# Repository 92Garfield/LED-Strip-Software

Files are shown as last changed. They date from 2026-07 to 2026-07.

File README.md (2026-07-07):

# gLED — WLAN LED Strip

NeoPixel strip on a Raspberry Pi Pico W (CircuitPython 9), controlled via browser extension.

## Folders

- `firmware/GEdge` — CIRCUITPY drive content (kitchen strip, 150 LEDs, `192.168.2.42`)
- `gLED-Client Chrome` — Chrome extension, **source of truth** for client `js/` + `css/`
- `gLED-Client Firefox` — Firefox extension (desktop + Android), only `manifest.json` differs
- `client/GEdge-html` — old on-controller web client (retired, kept for reference)

## Firmware (`firmware/GEdge`)

- Copy `src/config.example.py` to `src/config.py`, then set WiFi, IP, LED count, name, physical layout, and default animation
- `src/led_server.py` — HTTP server; serves one tiny HTML page exposing global `gLED`
- `src/animation_runner.py` — non-blocking animation loop beside the server
- `animations/*.py` — one class `Animation` per file (`start(now)` / `step(now)`)
  - `hue_cycle` — whole strip, hue rotates (interval + step configurable)
  - `fill_runner` — red runner right→left stacks until full, then back to blue
- `glib/color.py` — `hsv_to_rgb()` for NeoPixel
- Boot: connects WiFi, starts server, autostarts `config.DEFAULT_ANIMATION`

## HTTP API (`POST /data`, urlencoded, values NOT percent-encoded)

- `type=set` `data=r,g,b|r,g,b|…` — set all pixels (stops animation)
- `type=brightness` `data=1..100`
- `type=animation` `data=<name>` or `data=stop`
- `GET /` — HTML with `var gLED = {name, ledCount, length, physical, animations}`

## Clients (extensions)

- Run on the controller page, replace it entirely with their own UI
- Custom elements (`js/elements/`), built by `js/app.js`, dark CSS
- Show physical layout (y-up), tabs: Animation / Manual (tap LEDs to paint)
- No live data from server; last set state kept in `localStorage`
- Brightness slider in header

### Chrome

- `chrome://extensions` → Developer mode → Load unpacked → `gLED-Client Chrome`

### Firefox (desktop + Android)

- After client changes: run `gLED-Client Firefox/sync.ps1` (copies `js/`+`css/` from Chrome)
- Desktop test: `about:debugging` → Load Temporary Add-on
- Android: needs signed `.xpi` via addons.mozilla.org (unlisted) — see `gLED-Client Firefox/README.md`

## New controller / IP change

Update the IP in **3 places**:

- `gLED-Client Chrome/manifest.json` → `matches`
- `gLED-Client Firefox/manifest.json` → `matches` **and** `host_permissions`
- Firmware: `src/config.py` → `STATIC_IP`

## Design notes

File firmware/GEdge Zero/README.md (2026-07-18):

# GEdge Zero

HTTP-controlled WS2812/NeoPixel firmware for a **Raspberry Pi Zero family**
board (Zero W, Zero WH, Zero 2 W), driving up to **4 independent LED
strips** from the ["4-strips, 4-power" PCB](<../../PCB/simplified/4-strips, 4-power/pcb.md>).

This is the Pi Zero counterpart to [`../GEdge`](<../GEdge>) (which runs on a
Pico W under CircuitPython): same architecture (`src/` app code,
`animations/` step-based effects, `glib/` color helpers), but written in
regular Python 3 for Raspberry Pi OS, since the Pi Zero runs full Linux
rather than a microcontroller RTOS.

## Hardware

| Connector | GPIO (BCM) | Header pin | Peripheral | Firmware strip |
|---|---|---|---|---|
| J2 | GPIO18 | 12 | PWM0  | S1 |
| J4 | GPIO13 | 33 | PWM1  | S2 |
| J5 | GPIO10 | 19 | SPI0  | S3 |
| J3 | GPIO21 | 40 | PCM | S4 |

These four GPIOs were chosen because each is driven by a **different**
hardware peripheral capable of generating the WS2812 timing via DMA
(2x PWM, PCM, SPI) - so all four strips can run simultaneously without one
blocking another. See the PCB's `pcb.md` for the full board writeup, and
`J7-J10` for the power-only injection connectors on long strips.

## 1. Flash and boot Raspberry Pi OS

Use **Raspberry Pi OS Lite** (headless, no desktop) via Raspberry Pi
Imager. In the imager's settings (gear icon) before writing:
- Enable SSH
- Set your WiFi SSID/password
- Set a hostname/username/password

Boot the Pi and confirm you can SSH in:
```
ssh <username>@<hostname>.local
```

## 2. Enable SPI and free up the PCM/audio peripheral

Strip S3 (GPIO10) needs SPI enabled, and strip S4 (GPIO21) needs the
onboard audio disabled (it uses the same PCM peripheral and will conflict
with the LED timing otherwise).

```bash
sudo raspi-config
# Interface Options -> SPI -> Enable
```

Then edit `/boot/firmware/config.txt` (or `/boot/config.txt` on older OS
versions) and make sure audio is off:
```
dtparam=audio=off
```

Reboot after these changes: `sudo reboot`

## 3. Get the code onto the Pi

```bash
git clone <this repo's URL>
cd "LED-Strip-Software/firmware/GEdge Zero"
```

## 4. Install dependencies

`rpi_ws281x` needs root to access DMA/PWM, and building its C extension
needs a compiler - both are handled below.

```bash
sudo apt update
sudo apt install -y python3-pip python3-venv build-essential
python3 -m venv venv
source venv/bin/activate
pip install -r requirements.txt
```

## 5. Configure your strips

```bash
cp src/config.example.py src/config.py
nano src/config.py
```
Adjust `num_pixels`, `name`, `length_cm` and `physical` per strip to match
your actual strips (the GPIO/channel/dma values already match the PCB
table above - only change those if you rewired something).

## 6. Run it

`rpi_ws281x` requires root:

```bash
sudo venv/bin/python3 main.py
```

You should see each strip initialize and start its `DEFAULT_ANIMATIONS`
entry (rainbow by default). Visit `http://<hostname>.local/` from a
browser to confirm the server is up. The page is compatible with the gLED
Chrome/Firefox client: the first configured strip is exposed as the global
`gLED` object (and shown in the page body), additional strips as `gLED2`,
`gLED3`, `gLED4`; each object carries its `strip` value for the `/data`
field below.

### Control API

`POST /data` (form-encoded), same contract as GEdge, plus a `strip` field:

| Field | Values | Notes |
|---|---|---|
| `strip` | `S1`, `S2`, `S3`, `S4`, `all` | Which output to target. Defaults to `S1`. Ignored for `shutdown`. |
| `type` | `set`, `brightness`, `animation`, `shutdown` | `shutdown` powers off the Pi (safe to unplug once its LED stops blinking). |
| `data` | `"r,g,b\|r,g,b\|..."` (set) / `0-100` (brightness) / animation name or `stop` (animation) | Ignored for `shutdown`. |

## 7. Run automatically on boot (systemd)

Create `/etc/systemd/system/gedge-zero.service`:
```ini
[Unit]
Description=GEdge Zero LED controller
After=network-online.target

[Service]
Type=simple
WorkingDirectory=/home/<username>/LED-Strip-Software/firmware/GEdge Zero
ExecStart="/home/<username>/LED-Strip-Software/firmware/GEdge Zero/venv/bin/python3" main.py
Restart=on-failure
User=root

[Install]
WantedBy=multi-user.target
```

Then:
```bash
sudo systemctl daemon-reload
sudo systemctl enable --now gedge-zero.service
sudo journalctl -u gedge-zero -f   # follow logs
```

## Troubleshooting

- **`ws2811_init failed`**: another process is already using that DMA
  channel/peripheral, or SPI/audio wasn't configured per step 2. Check
  `dmesg` and confirm `dtparam=audio=off` and SPI is enabled.
- **Flicker / glitches on GPIO10 or GPIO21**: these carry 3.3 V logic
  straight into nominally-5 V strips (no level shifter on the simplified
  PCB) - keep data leads short, as noted in the PCB's `pcb.md`.
- **Strips don't turn off when you stop the script**: use `Ctrl+C` (SIGINT)
  or `systemctl stop`, not `kill -9` - the signal handler in `main.py`
  clears all strips on exit; `SIGKILL` skips it.

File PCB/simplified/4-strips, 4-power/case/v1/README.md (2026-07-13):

# 3D-printed case v1 — gLED Controller simple

Two-part case for `../../led-controller-simple.kicad_pcb`: a **tray** the PCB
screws into and a **friction-fit lid** with openings above every top-entry
connector. Outer size **90.8 × 75.8 × 34.4 mm** (tray + lid).

All geometry is parametric in `case.scad`; positions are copied from
`build_board.py` in KiCad board coordinates and mirrored automatically.

## Files

- `case.scad` — source (OpenSCAD 2021.01). `part` selects what to render:
  `"tray"`, `"lid"` (already flipped for printing) or `"assembly"`
  (tray + ghost board + hovering lid, for visual checks only).
- `case_tray.stl`, `case_lid.stl` — ready to slice, in print orientation.
- `preview_*.png` — renders of the assembly and both printable parts.

## Openings

| Where | For |
|---|---|
| Lid, right slot | J2–J5 strip plugs + wires (top-entry JST XH) |
| Lid, left slot | J7–J10 power-only plugs |
| Lid + top wall notch | J1 screw terminal: screwdriver from above, supply wires out of the top edge |
| Bottom wall slot | Pi Zero mini-HDMI / USB ports (Pi hangs under the PCB) |
| Left wall slot | Pi SD card |

## Printing

- No supports needed for either part; lid STL is already face-down.
- PLA or PETG, 0.2 mm layers, 3 perimeters. ~25 % infill is plenty.
- The lid lip has 0.3 mm clearance (`lip_clr`) — tighten/loosen to taste.

## Assembly

1. Mount the Pi on its M2.5 standoffs under the PCB (11 mm board-to-board).
2. Drop the PCB in and fasten with **4× M3 self-tapping screws** (8–10 mm)
   into the corner bosses (pilot holes Ø2.7 mm).
3. Wire J1 through the top-edge notch, plug in strips, press the lid on.

## Regenerating

```
openscad -o case_tray.stl -D "part=\"tray\"" case.scad
openscad -o case_lid.stl  -D "part=\"lid\""  case.scad
```

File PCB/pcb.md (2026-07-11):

# LED Controller PCB — KiCad files

Carrier board for a Raspberry Pi Zero 2 WH: 110 × 70 mm, 2 layers, 2 oz copper.
The board sits **on top of** the Pi like an oversized pHAT — the 2×20 socket is
on the back side, the Pi hangs underneath on M2.5 standoffs with its pins
pointing up into the socket. Design intent and part choices are in `plan.md`;
this file explains what each generated file is and what it means electrically.

## Source files

### `build_board.py`
The actual "source code" of the board. Running it with KiCad's bundled Python
regenerates `led-controller.kicad_pcb` from scratch — every footprint position,
net assignment, trace, zone and silkscreen label is defined here as code.
If you want to change the layout, change this script, not the `.kicad_pcb`
(manual edits in KiCad get overwritten on the next script run).

```
"D:/Program Files/KiCad/10.0/bin/python.exe" build_board.py
"D:/Program Files/KiCad/10.0/bin/python.exe" fill_zones.py
```

Electrically, the script defines these nets:

| Net | Meaning |
|---|---|
| `+5V` | Raw supply from J1. Feeds the Pi (header pins 2/4), U1's VCC, and all four fuse inputs. Distributed as wide copper pours, not traces, because worst case is ~20 A. |
| `GND` | Common return. Poured on both layers, stitched with vias. |
| `5V_S1`…`5V_S4` | The four **fused** 5 V outputs — everything after fuse Fx belongs to its own net so a blown fuse isolates exactly one strip. |
| `D18_3V3`, `D13_3V3`, `D10_3V3`, `D21_3V3` | 3.3 V logic from the Pi GPIOs (18/13/10/21) into the level shifter inputs. |
| `D1_5V`…`D4_5V` | 5 V logic out of the 74AHCT125, before the series resistor. |
| `DATA1`…`DATA4` | After the 470 Ω resistor, into JST pin 2 — what the first LED of each strip sees. |

Channel mapping (matches `plan.md` and the firmware): GPIO18 → S1/J2,
GPIO13 → S2/J3, GPIO10 → S3/J4, GPIO21 → S4/J5.

### `fill_zones.py`
Refills the copper zones after a rebuild. Separate script because KiCad's zone
filler crashes when called on a freshly built in-memory board (standalone
Python quirk) — it must load the saved file, fill, and save again. **Zones must
be filled** before export: unfilled zones would mean the Gerbers contain no
+5V/GND copper at all.

## Board files

### `led-controller.kicad_pcb`
The board itself — open this in KiCad (PCB Editor) to inspect or measure.
Layout, electrically:

- **Front (F.Cu), +5V pours**: a top strip from J1 across the board, a left
  strip feeding the Pi's 5 V pins, and a ~12 mm vertical bus feeding all four
  fuse inputs. Sized for 20 A total at 2 oz copper; the bus connects to the
  fuse clips solid (no thermal spokes) to minimize resistance.
- **Fuse rows**: each 5×20 mm fuse lies directly in line with its JST
  connector, so the fused current path is fuse clip → 2 mm trace → JST pin 1,
  a few millimetres long. No fused current crosses the rest of the board.
- **Data path**: Pi GPIO (through-hole header pads) → short front-side traces
  → 74AHCT125 inputs. The shifted 5 V outputs run on the **back** layer to the
  470 Ω resistors (also mounted on the back, next to the JSTs) → JST pin 2.
  Resistors sit close to the connectors on purpose: they damp reflections at
  the cable, which only works near the line's driving end.
- **GND**: full pours on both layers plus ~20 stitching vias. LED return
  current flows from JST pin 3 through these planes back to J1. The unused
  74AHCT125 enable pins (1, 4, 10, 13) are tied to GND via the back pour —
  outputs permanently enabled.
- **Mounting**: H1–H4 are the M2.5 Pi-pattern holes (58 × 23 mm), H5–H8 are M3
  case-mounting corner holes. All holes are unplated and carry no net.

### `led-controller.kicad_pro` / `.kicad_prl` / `~*.lck`
KiCad project settings, per-user display state, and an editor lock file.
No electrical content; the `.lck` just means the board is open in KiCad.
None of these are needed for manufacturing.

## Manufacturing outputs

### `gerbers/` and `led-controller-gerbers.zip`
The zip is what you upload to the fab (JLCPCB etc.) — it contains exactly the
files in `gerbers/`. Gerbers are the fab's ground truth; they describe
photomask geometry per layer, with no nets or components:

| File | Layer | Electrical meaning |
|---|---|---|
| `*-F_Cu.gtl` | Front copper | All top-side conductors: +5V pours, fused-output traces, data input traces, GND fill. |
| `*-B_Cu.gbl` | Back copper | Bottom conductors: GND plane, level-shifter output traces, resistor connections. |
| `*-F_Mask.gts` / `*-B_Mask.gbs` | Solder mask | *Openings* in the green coating — where copper is exposed for soldering. Everything else stays insulated. |
| `*-F_Silkscreen.gto` / `*-B_Silkscreen.gbo` | Silkscreen | Ink only, no electrical function: reference designators, `+`/`−` polarity at J1, `+`/`D`/`G` pinout at each JST, fuse ratings, Pi placement outline on the back. |
| `*-Edge_Cuts.gm1` | Board outline | Where the board is routed out — the 110 × 70 mm contour. |
| `*.drl` | Excellon drill | Every hole: plated through-holes (component pins and vias, walls metallized so they conduct between layers) and the non-plated mounting holes. |
| `*-drl_map.gbr`, `*-job.gbrjob` | Drill map / job file | Documentation for the fab; no copper. |

**Ordering note:** select **2 oz outer copper**. The pour widths were sized for
that; at standard 1 oz the +5V distribution would run roughly twice as warm.

### `bom.csv`
Parts list with LCSC part numbers, JLCPCB BOM format. Quantities note: 8 fuse
clips (2 per position); the 5 A glass fuses themselves are bought separately.
U1 is listed as the hand-solderable DIP — swap to SN74AHCT125DR (SOIC-14) if
ordering assembly.

## Verification artifacts

- `drc.json` — last design-rule-check report: **0 errors, 0 unconnected
  items** (remaining warnings are silkscreen cosmetics). Regenerate with
  `kicad-cli pcb drc --format json --output drc.json led-controller.kicad_pcb`.
- `render_top.png` / `render_bottom.png` — 3D renders for a quick visual check
  without opening KiCad.

## Regenerating everything

```
cd PCB
"D:/Program Files/KiCad/10.0/bin/python.exe" build_board.py
"D:/Program Files/KiCad/10.0/bin/python.exe" fill_zones.py
kicad-cli pcb drc --format json --output drc.json led-controller.kicad_pcb
kicad-cli pcb export gerbers --layers F.Cu,B.Cu,F.Mask,B.Mask,F.Silkscreen,B.Silkscreen,Edge.Cuts --subtract-soldermask --output gerbers/ led-controller.kicad_pcb
kicad-cli pcb export drill --format excellon --drill-origin absolute --generate-map --map-format gerberx2 --output gerbers/ led-controller.kicad_pcb
```

Close the board in KiCad first — the build overwrites `led-controller.kicad_pcb`.

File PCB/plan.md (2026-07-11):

# LED Controller PCB

Carrier board for a Raspberry Pi Zero 2 W(H): takes 5 V from a power supply,
powers the Pi, level-shifts the data signals to 5 V and feeds up to four
WS2812-style strips through pluggable, individually fused connectors.

## Schematic (simplified)

### Power

```
                     C1
J1 +5V ────●────────1000µF───┐
           │                (GND)
           ├──────────────────────────► Pi 5V      (header pins 2 & 4)
           ├──[ F1 5A ]───────────────► J2 pin 1   +5V strip 1
           ├──[ F2 5A ]───────────────► J3 pin 1   +5V strip 2
           ├──[ F3 5A ]───────────────► J4 pin 1   +5V strip 3
           └──[ F4 5A ]───────────────► J5 pin 1   +5V strip 4

J1 GND ── ground plane ── Pi GND ── U1 GND ── J2..J5 pin 3
```

Mind the polarity at J1 — a reversed supply kills the Pi. Mark +/− clearly
on the silkscreen.

### Data (one of four identical channels)

```
Pi GPIO18 ────► U1 input      U1 output ───[ R1 470Ω ]───► J2 pin 2  DATA
(3.3 V logic)   └─ 74AHCT125, VCC = 5 V ─┘    (5 V logic)
                   + C2 100nF at VCC pin
```

Channel mapping: GPIO18 → J2, GPIO13 → J3, GPIO10 → J4, GPIO21 → J5.
(`rpi_ws281x` drives GPIO18/GPIO13 as PWM0/PWM1 simultaneously; GPIO10 = SPI
and GPIO21 = PCM are alternative single-channel outputs.)

## Parts

| Ref | Part | Why | JLCPCB |
|---|---|---|---|
| J1 | Screw terminal 5.08 mm 2P (KF301-5.0-2P) | 5 V power input, takes thick wire for high current | [C474881](https://jlcpcb.com/parts/componentSearch?searchTxt=C474881) |
| J2–J5 | JST XH 3-pin header (B3B-XH-A) | Pluggable strip outputs (+5V / DATA / GND) | [C144394](https://jlcpcb.com/parts/componentSearch?searchTxt=C144394) |
| J6 | Female header 2×20, 2.54 mm | Socket the Pi Zero 2 WH plugs into | [C2977589](https://jlcpcb.com/parts/componentSearch?searchTxt=C2977589) |
| U1 | SN74AHCT125N (DIP-14) | Shifts 3.3 V GPIO data to 5 V, one buffer per strip | [C354152](https://jlcpcb.com/parts/componentSearch?searchTxt=C354152) |
| R1–R4 | 470 Ω, 0805 | Protects first LED, damps ringing on the data line | [C17710](https://jlcpcb.com/parts/componentSearch?searchTxt=C17710) |
| C1 | 1000 µF 16 V electrolytic | Bulk capacitor: absorbs inrush and load spikes | [C43832](https://jlcpcb.com/parts/componentSearch?searchTxt=C43832) |
| C2 | 100 nF, 0805 | Decoupling for U1 | [C49678](https://jlcpcb.com/parts/componentSearch?searchTxt=C49678) |
| F1–F4 | 5×20 mm fuse clips (2 per fuse) + 5 A glass fuse | Per-strip overcurrent protection | [C3130](https://jlcpcb.com/parts/componentSearch?searchTxt=C3130) |

## Layout notes

- **Copper:** order 2 oz. Route +5V and GND as wide pours, not traces
  (4 strips × 5 A worst case at the input). See the PCB-trace mode of the
  wire calculator for widths.
- **Mounting:** 4× M2.5 holes matching the Pi Zero footprint (standoffs — the
  2×20 header must not carry mechanical load), plus corner holes for the case.
- **C1** close to J1; one extra electrolytic per strip connector is cheap
  insurance if strips are long.
- **R1–R4** as close to their JST connectors as possible.
- **Fuse rating:** 5 A ≈ 80 LEDs at full white; adjust to your strips. Strips
  longer than ~1–2 m should get power injected at the far end through their
  own wiring, not through the data pigtail.
- **Connector note:** most strips ship with JST **SM** pigtails (wire-to-wire).
  Either crimp XH plugs onto the strip wires or buy XH pigtails and solder
  them to the strips.
- U1 is the through-hole DIP variant for easy hand-soldering; if JLCPCB
  assembles the board, use the SOIC-14 version (SN74AHCT125DR) instead.

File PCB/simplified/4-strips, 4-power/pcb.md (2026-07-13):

# LED Controller PCB — simplified variant

Bare-minimum version of `../led-controller.kicad_pcb` for hand assembly:
the 5 V screw terminal (J1, horizontally centered on the top edge), four JST
strip connectors (J2–J5, right edge), four **power-only** JST connectors
(J7–J10, left edge) and the 2×20 socket for the Pi Zero 2 WH (J6).
85 × 70 mm, 2 layers, 2 oz copper. Same carrier concept as the full board:
the socket sits on the **back**, the Pi hangs underneath on M2.5 standoffs
with its pins pointing up into it.

J7–J10 use the **same JST XH socket** as J2–J5 (one part type to buy), but
only +5 V (pin 1, top) and GND (pin 3, bottom) are wired — the middle data
pin is unconnected. Use them to inject power mid-strip or at the far end
of long strips.

Only 10 solder parts, all through-hole — a 20-minute soldering job.

## Deliberately readable layout

The copper is arranged so you can verify everything by eye from the renders:

- **Back layer = one solid GND plane, nothing else.** No traces, no vias.
  Every GND pin (J1 pin 2, the Pi's ground pins, each JST `G` pin) reaches
  the plane through its own through-hole.
- **Front layer = only +5V areas + the four data traces.** Any copper you
  see on top is +5V: a **ring around all four board edges** fed by J1 at
  the top center, plus an arm from the left edge to the Pi's 5 V pins
  (header pins 2/4). The ring feeds every JST `+` pin on both sides. Each
  edge carries a `+5V` silkscreen label.
- **All four data traces run on the front**, GPIO pin → JST `D` pin, fully
  visible, no layer changes, no crossings.

Routing all data on one side without crossings forces the connector order
to follow the header pin geometry. Top to bottom the connectors are:

| Connector | GPIO | Pi header pin | Firmware strip |
|---|---|---|---|
| J2 (top) | GPIO18 | 12 | S1 |
| J3 | GPIO21 | 40 | S4 |
| J4 | GPIO13 | 33 | S2 |
| J5 (bottom) | GPIO10 | 19 | S3 |

Note this is **not** S1→S4 in order — each connector's silkscreen states its
GPIO and strip number, so plug strips by label, not by position.

The left-edge column J7 (top) → J10 (bottom) mirrors the right column but
carries **no data**: `+` on the top pin, `G` on the bottom pin, middle pin
open. The silkscreen marks the polarity at each connector.

## What was removed vs. the full board, and what that means

| Removed | Consequence |
|---|---|
| Fuses F1–F4 | JST `+` pins are fed **directly** from the +5V pour. A short in a strip or cable is limited only by your PSU. Put a fuse in the supply wire before J1 (or use a PSU with proper overcurrent protection). |
| 74AHCT125 level shifter | Data pins carry **3.3 V logic straight from the GPIOs** into nominally-5 V strips. WS2812B usually accept this when the data lead is short (< ~1 m) and power/ground are solid. If a strip glitches, shorten the lead or drop strip VCC slightly (e.g. one diode) — or use the full board. |
| 470 Ω series resistors | No reflection damping at the cable. Another reason to keep strip leads short. |
| 1000 µF bulk cap + 100 nF | Add a bulk electrolytic at the strip or PSU end if you see flicker on load steps. |

## Files

- `build_board.py` — the source of truth; regenerates the `.kicad_pcb` from
  scratch (same workflow as the full board, see `../pcb.md`).
- `fill_zones.py` — refills copper zones after a rebuild (must run, or the
  Gerbers contain no +5V/GND copper).
- `led-controller-simple.kicad_pcb` — the board; open in KiCad to inspect.
- `gerbers/`, `led-controller-simple-gerbers.zip` — upload the zip to the fab.
- `drc.json` — DRC report: **0 errors, 0 warnings, 0 unconnected items**.
- `render_top.png` / `render_bottom.png` — 3D renders.
- `bom.csv` — the three connector types (plus standoffs); 8× JST XH total.
- `case/v1/` — 3D-printable case (OpenSCAD source + STLs), see its README.

## Regenerating

```
cd "PCB/simplified/4-strips, 4-power"
"D:/Program Files/KiCad/10.0/bin/python.exe" build_board.py
"D:/Program Files/KiCad/10.0/bin/python.exe" fill_zones.py
kicad-cli pcb drc --format json --output drc.json led-controller-simple.kicad_pcb
kicad-cli pcb export gerbers --layers F.Cu,B.Cu,F.Mask,B.Mask,F.Silkscreen,B.Silkscreen,Edge.Cuts --subtract-soldermask --output gerbers/ led-controller-simple.kicad_pcb
kicad-cli pcb export drill --format excellon --drill-origin absolute --generate-map --map-format gerberx2 --output gerbers/ led-controller-simple.kicad_pcb
```

**Ordering note:** still select **2 oz outer copper** — the +5V pours are
sized for ~20 A total at 2 oz.

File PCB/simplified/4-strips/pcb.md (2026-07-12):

# LED Controller PCB — simplified variant

Bare-minimum version of `../led-controller.kicad_pcb` for hand assembly:
**only** the 5 V screw terminal (J1), four JST strip connectors (J2–J5) and
the 2×20 socket for the Pi Zero 2 WH (J6). 85 × 70 mm, 2 layers, 2 oz copper.
Same carrier concept as the full board: the socket sits on the **back**, the
Pi hangs underneath on M2.5 standoffs with its pins pointing up into it.

Only 6 solder parts, all through-hole — a 15-minute soldering job.

## Deliberately readable layout

The copper is arranged so you can verify everything by eye from the renders:

- **Back layer = one solid GND plane, nothing else.** No traces, no vias.
  Every GND pin (J1 pin 2, the Pi's ground pins, each JST `G` pin) reaches
  the plane through its own through-hole.
- **Front layer = only +5V areas + the four data traces.** Any copper you
  see on top is +5V: a top strip from J1, a left strip feeding the Pi's 5 V
  pins (header pins 2/4), and a right strip feeding every JST `+` pin.
  Each area carries a `+5V` silkscreen label.
- **All four data traces run on the front**, GPIO pin → JST `D` pin, fully
  visible, no layer changes, no crossings.

Routing all data on one side without crossings forces the connector order
to follow the header pin geometry. Top to bottom the connectors are:

| Connector | GPIO | Pi header pin | Firmware strip |
|---|---|---|---|
| J2 (top) | GPIO18 | 12 | S1 |
| J3 | GPIO21 | 40 | S4 |
| J4 | GPIO13 | 33 | S2 |
| J5 (bottom) | GPIO10 | 19 | S3 |

Note this is **not** S1→S4 in order — each connector's silkscreen states its
GPIO and strip number, so plug strips by label, not by position.

## What was removed vs. the full board, and what that means

| Removed | Consequence |
|---|---|
| Fuses F1–F4 | JST `+` pins are fed **directly** from the +5V pour. A short in a strip or cable is limited only by your PSU. Put a fuse in the supply wire before J1 (or use a PSU with proper overcurrent protection). |
| 74AHCT125 level shifter | Data pins carry **3.3 V logic straight from the GPIOs** into nominally-5 V strips. WS2812B usually accept this when the data lead is short (< ~1 m) and power/ground are solid. If a strip glitches, shorten the lead or drop strip VCC slightly (e.g. one diode) — or use the full board. |
| 470 Ω series resistors | No reflection damping at the cable. Another reason to keep strip leads short. |
| 1000 µF bulk cap + 100 nF | Add a bulk electrolytic at the strip or PSU end if you see flicker on load steps. |

## Files

- `build_board.py` — the source of truth; regenerates the `.kicad_pcb` from
  scratch (same workflow as the full board, see `../pcb.md`).
- `fill_zones.py` — refills copper zones after a rebuild (must run, or the
  Gerbers contain no +5V/GND copper).
- `led-controller-simple.kicad_pcb` — the board; open in KiCad to inspect.
- `gerbers/`, `led-controller-simple-gerbers.zip` — upload the zip to the fab.
- `drc.json` — DRC report: **0 errors, 0 warnings, 0 unconnected items**.
- `render_top.png` / `render_bottom.png` — 3D renders.
- `bom.csv` — the three connector types (plus standoffs).

## Regenerating

```
cd PCB/simplified
"D:/Program Files/KiCad/10.0/bin/python.exe" build_board.py
"D:/Program Files/KiCad/10.0/bin/python.exe" fill_zones.py
kicad-cli pcb drc --format json --output drc.json led-controller-simple.kicad_pcb
kicad-cli pcb export gerbers --layers F.Cu,B.Cu,F.Mask,B.Mask,F.Silkscreen,B.Silkscreen,Edge.Cuts --subtract-soldermask --output gerbers/ led-controller-simple.kicad_pcb
kicad-cli pcb export drill --format excellon --drill-origin absolute --generate-map --map-format gerberx2 --output gerbers/ led-controller-simple.kicad_pcb
```

**Ordering note:** still select **2 oz outer copper** — the +5V pours are
sized for ~20 A total at 2 oz.

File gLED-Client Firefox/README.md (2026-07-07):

# gLED Client — Firefox (desktop + Android)

Same extension as `gLED-Client Chrome`; `js/` and `css/` are copies of the
Chrome folder (the source of truth). After changing anything there, run
`./sync.ps1` here. Only `manifest.json` is Firefox-specific
(`browser_specific_settings` with the gecko ID, min version 128 for
`world: "MAIN"` content scripts).

New controller? Add its IP to `matches` AND `host_permissions` in
`manifest.json` (and in the Chrome manifest).

## Try it on desktop (temporary, no signing)

1. Firefox → `about:debugging#/runtime/this-firefox`
2. "Load Temporary Add-on…" → pick this folder's `manifest.json`
3. Visit `http://192.168.2.42/`. Gone after a restart of Firefox.

## Install permanently / on Android (needs Mozilla signing)

Android Firefox only installs signed extensions, so a one-time setup:

1. Zip the contents of this folder (manifest.json at the zip root, not the
   folder itself), e.g. `web-ext build` (`npm i -g web-ext`).
2. Create a (free) account at https://addons.mozilla.org, then
   Developer Hub → "Submit a New Add-on" → choose **"On your own"**
   (unlisted / self-distribution) → upload the zip.
3. After the automatic review you can download the signed `.xpi`.
4. On the phone: open the `.xpi` URL/file in Firefox for Android and confirm
   the install prompt. If nothing happens, put the `.xpi` somewhere
   reachable over http and open that link in Firefox.
5. Grant the site permission if asked (Extensions → gLED Client → Permissions).

Every update needs a version bump in `manifest.json` and a re-upload for
signing. For quick experiments on Android without signing, Firefox Nightly +
a custom add-on collection also works (Settings → About → tap the logo 5x →
Custom Add-on collection).

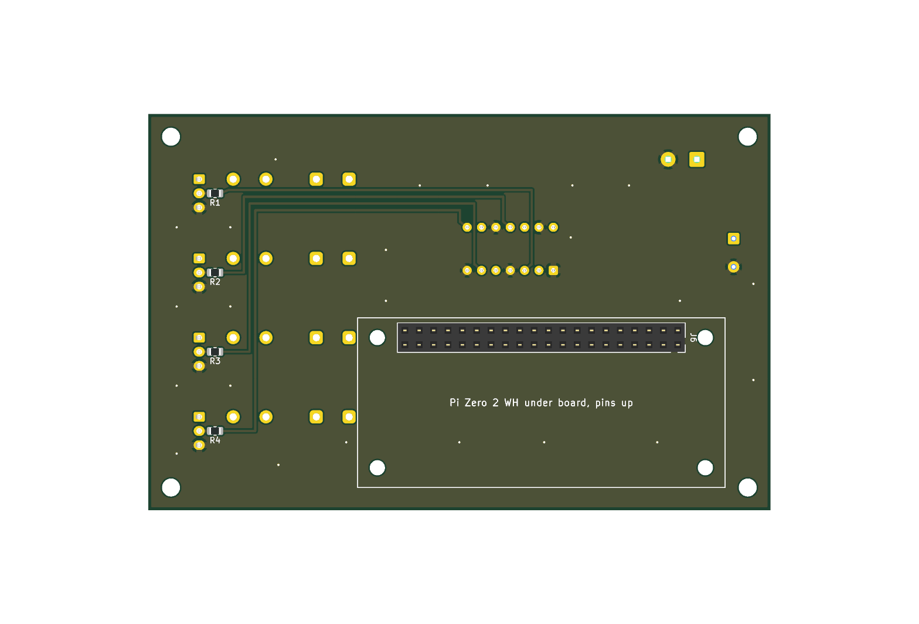
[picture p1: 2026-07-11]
PCB/render_bottom.png

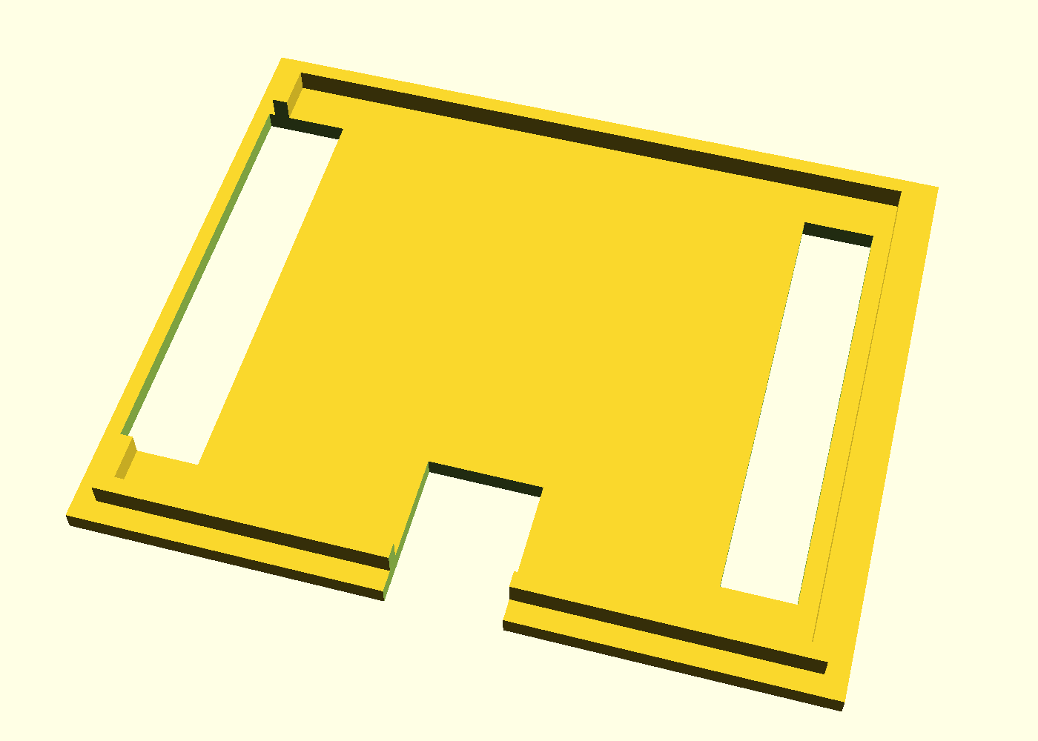
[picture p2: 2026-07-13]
PCB/simplified/4-strips, 4-power/case/v1/preview_lid.png

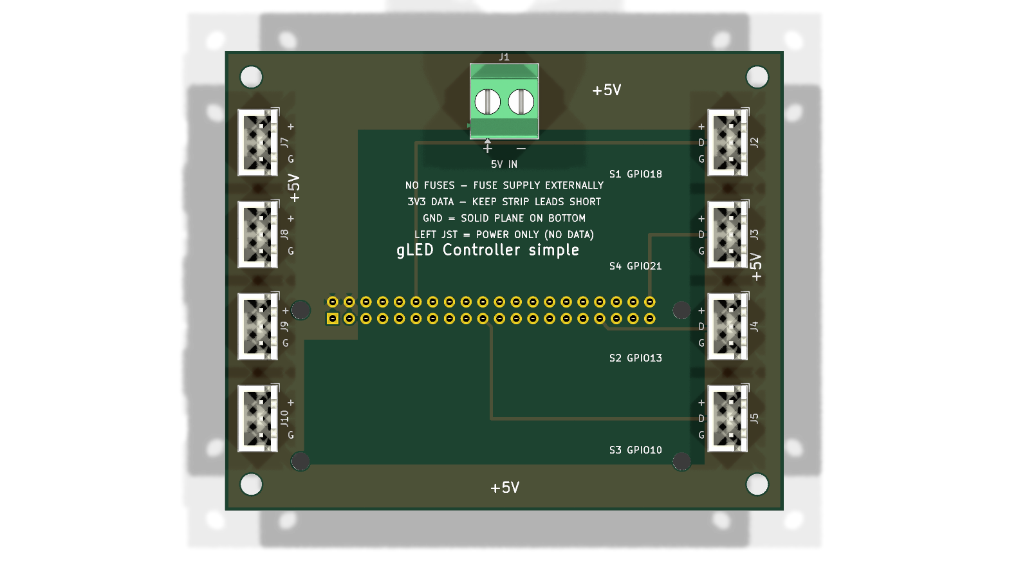
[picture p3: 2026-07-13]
PCB/simplified/4-strips, 4-power/render_top.png

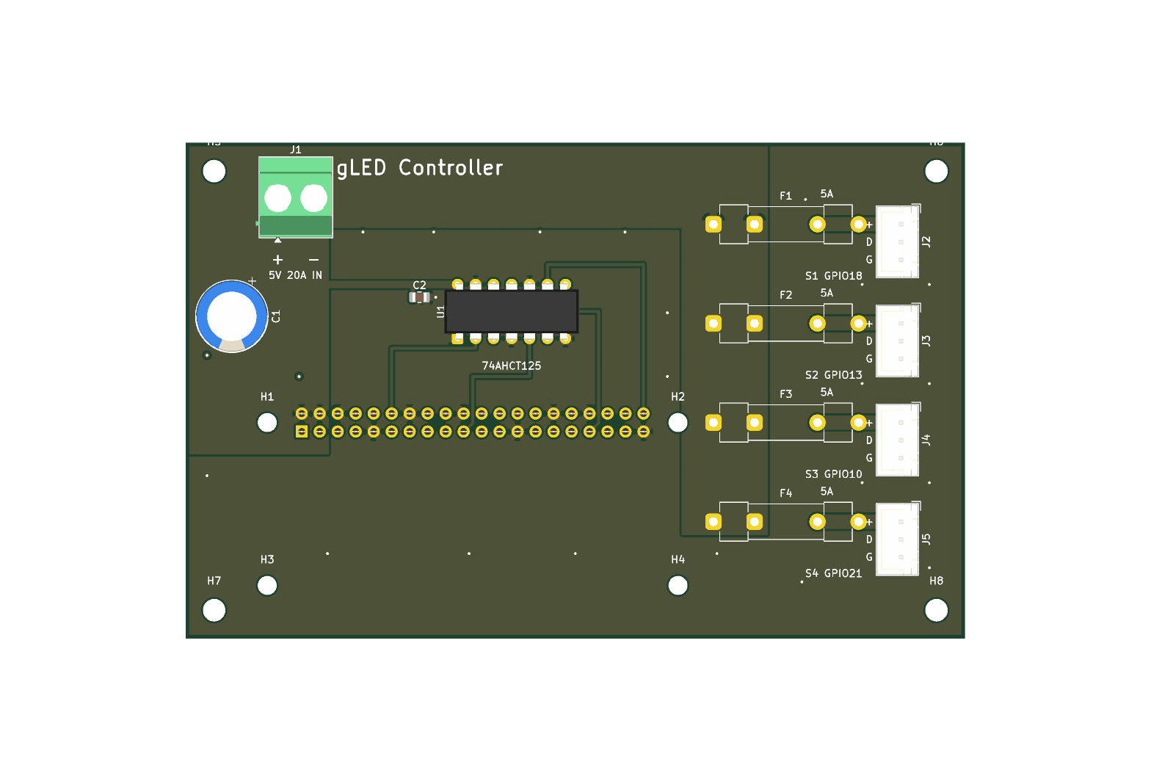
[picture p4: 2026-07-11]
PCB/render_top.png

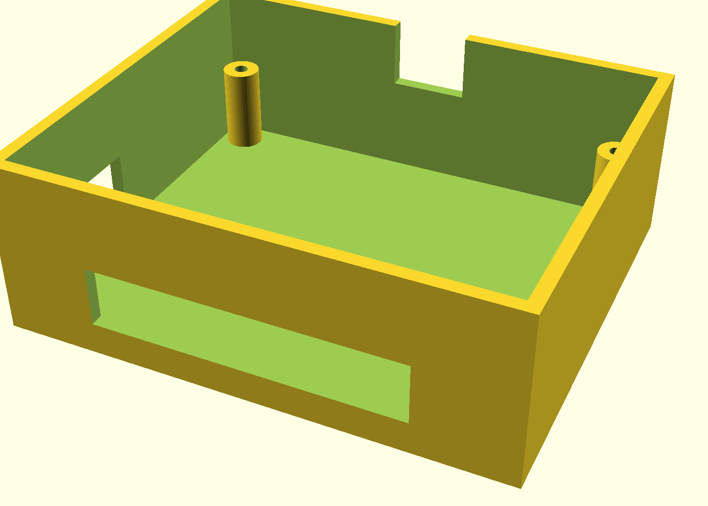
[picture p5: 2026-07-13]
PCB/simplified/4-strips, 4-power/case/v1/preview_tray.png

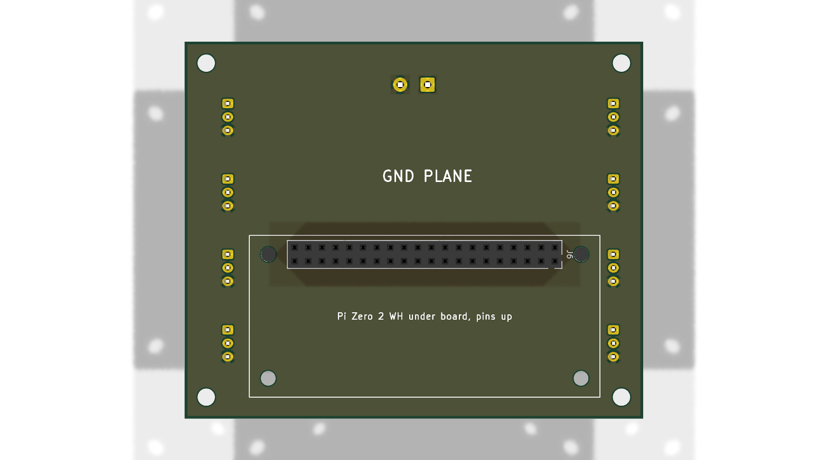
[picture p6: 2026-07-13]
PCB/simplified/4-strips, 4-power/render_bottom.png

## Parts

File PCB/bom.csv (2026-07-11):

Comment | Designator | Footprint | Quantity | LCSC Part # | Notes
Screw terminal 5.08mm 2P (KF301-5.0-2P) | J1 | TB-5.08-2P | 1 | C474881 | 5V power input; mark +/- on silkscreen
JST XH 3-pin header (B3B-XH-A) | J2,J3,J4,J5 | JST-XH-3P vertical THT | 4 | C144394 | Strip outputs: +5V / DATA / GND
Female header 2x20 2.54mm | J6 | PinSocket 2x20 P2.54mm | 1 | C2977589 | Socket for Pi Zero 2 WH
SN74AHCT125N | U1 | DIP-14 | 1 | C354152 | Level shifter; use SN74AHCT125DR (SOIC-14, C7470) if JLCPCB assembles
470R 0805 | R1,R2,R3,R4 | R0805 | 4 | C17710 | Series resistor on each data line; place close to J2-J5
1000uF 16V electrolytic | C1 | CAP-TH 10x12.5mm P5.00mm | 1 | C43832 | Bulk capacitor; place close to J1
100nF 0805 | C2 | C0805 | 1 | C49678 | Decoupling at U1 VCC pin
Fuse clip 5x20mm | F1,F2,F3,F4 | Fuse clip 5x20mm THT | 8 | C3130 | 2 clips per fuse position
Glass fuse 5x20mm 5A | F1,F2,F3,F4 | 5x20mm cartridge | 4 |  | Not stocked for assembly; buy separately and adjust rating to your strips

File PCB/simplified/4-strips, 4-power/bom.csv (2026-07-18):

Comment | Designator | Footprint | Quantity | LCSC Part # | Notes
Screw terminal 5.08mm 2P (KF301-5.0-2P) | J1 | TB-5.08-2P | 1 | C474881 | 5V power input; mark +/- on silkscreen
JST XH 3-pin header (B3B-XH-A) | J2,J3,J4,J5,J7,J8,J9,J10 | JST-XH-3P vertical THT | 8 | C144394 | J2-J5: strip outputs +5V / DATA / GND; J7-J10: power only (+5V / GND, data pin unconnected)
Female header 2x20 2.54mm | J6 | PinSocket 2x20 P2.54mm | 1 | C2977589 | Socket for Pi Zero 2 WH; solder on the BACK side

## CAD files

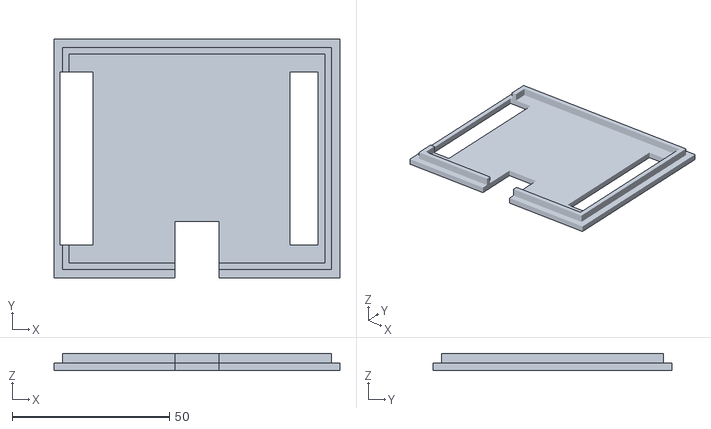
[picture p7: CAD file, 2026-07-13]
PCB/simplified/4-strips, 4-power/case/v1/case_lid.stl
90.8 x 75.8 x 5.40

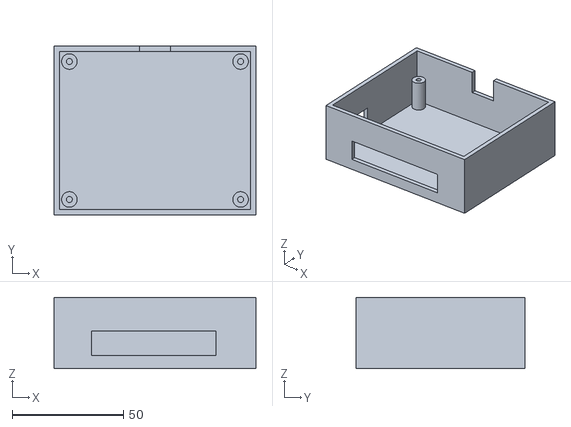
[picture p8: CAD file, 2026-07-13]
PCB/simplified/4-strips, 4-power/case/v1/case_tray.stl
90.8 x 75.8 x 32.0

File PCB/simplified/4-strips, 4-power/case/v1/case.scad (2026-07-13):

// 3D-printable case for "gLED Controller simple" (led-controller-simple.kicad_pcb)
// -------------------------------------------------------------------------------
// Two parts: a TRAY the PCB screws into (M3 self-tapping into corner bosses,
// same holes H5-H8 the board already has) and a friction-fit LID with openings
// above every top-entry connector.
//
// The Pi Zero 2 WH hangs UNDER the PCB (socket on the PCB back, Pi on M2.5
// standoffs), so the tray provides 16 mm of depth below the board plus port /
// SD-card openings in the lower walls.
//
// All positions are taken from build_board.py and entered in KICAD board
// coordinates (origin at board top-left, y pointing DOWN). The krect() helper
// flips y so the printed case matches the physical board.
//
// Render:
//   part = "tray"      -> printable tray (prints as modeled, no supports)
//   part = "lid"       -> printable lid  (already flipped flat on the bed)
//   part = "assembly"  -> tray + ghost board + lid hovering (visual check only)

part = "assembly";

// ---------------- board facts (kicad coords, mm) ----------------
W  = 85;      // board size
H  = 70;
PCB_T = 1.6;

M3_HOLES = [[4, 4], [81, 4], [4, 66], [81, 66]];   // H5-H8

JY = [11.5, 25.5, 39.5, 53.5];   // JST pin-1 rows (both columns)
// JST XH body bounding boxes (from footprint courtyard, minus its 0.25 margin)
JST_R = [73.3, 79.6];            // right column J2-J5, body x-range
JST_L = [1.8, 8.15];             // left column J7-J10, body x-range
JST_DY = [-2.7, 7.7];            // body y-range relative to pin-1 row
JST_HT = 7.0;                    // body height above PCB

J1_BOX = [37.1, 1.8, 47.9, 13.6];  // terminal block body x0,y0,x1,y1
J1_HT  = 10.3;

// Pi Zero 2 WH under the board: top face 11 mm below PCB bottom
PI_BOX  = [8, 36, 73, 66];       // outline in board coords
PI_DROP = 11;                    // PCB bottom -> Pi component face
PI_T    = 1.6;
// port centers on the Pi edge that faces the board's bottom edge (y = 70):
// mini-HDMI x=20.4, USB-OTG x=49.4, USB-PWR x=62 (board coords)

// ---------------- case parameters ----------------
clr     = 0.5;    // gap board edge -> inner wall
wall    = 2.4;
floor_t = 2.4;
below   = 16;     // interior floor -> PCB bottom (socket 8.5 + Pi 11+1.6 + air)
above   = 12;     // PCB top -> wall top (J1 is 10.3 tall)
boss_d  = 7;
pilot_d = 2.7;    // M3 self-tapping
pilot_depth = 9;

lid_t   = 2.4;
lip_h   = 3;      // friction lip reaching into the tray
lip_w   = 2;
lip_clr = 0.3;    // lip -> inner wall clearance

$fn = 48;

// ---------------- derived ----------------
pcb_bot  = below;            // z of PCB underside (z=0 = interior floor)
pcb_top  = below + PCB_T;
wall_top = pcb_top + above;

ix0 = -clr;      ix1 = W + clr;      // interior cavity
iy0 = -clr;      iy1 = H + clr;
ox0 = ix0 - wall; ox1 = ix1 + wall;  // outer shell
oy0 = iy0 - wall; oy1 = iy1 + wall;

echo(str("outer size: ", ox1 - ox0, " x ", oy1 - oy0, " x ",
         floor_t + wall_top + lid_t, " mm (tray + lid)"));

// cube from kicad-coordinate corners (flips y), z absolute
module krect(x0, y0, x1, y1, z0, z1) {
    translate([x0, H - y1, z0]) cube([x1 - x0, y1 - y0, z1 - z0]);
}

// ---------------- tray ----------------
module tray() {
    difference() {
        union() {
            // shell with floor, cavity carved out
            difference() {
                translate([ox0, H - iy1 - wall, -floor_t])
                    cube([ox1 - ox0, oy1 - oy0, floor_t + wall_top]);
                krect(ix0, iy0, ix1, iy1, 0, wall_top + 1);
            }
            // corner bosses the PCB screws onto
            for (p = M3_HOLES)
                translate([p[0], H - p[1], 0]) cylinder(d = boss_d, h = below);
        }
        // J1 wire/screwdriver notch, wall at the board's top edge
        krect(35.5, -clr - wall - 1, 49.5, 1, pcb_top, wall_top + 1);
        // Pi port slot (mini-HDMI / USB), wall at the board's bottom edge
        krect(14, H - 1, 70, H + clr + wall + 1, 3.5, 14.5);
        // SD-card slot, left wall
        krect(-clr - wall - 1, 41, 1, 61, 3.5, 14.5);
        // pilot holes in the bosses
        for (p = M3_HOLES)
            translate([p[0], H - p[1], below - pilot_depth])
                cylinder(d = pilot_d, h = pilot_depth + 1);
    }
}

// ---------------- lid (modeled in mounted position) ----------------
module lid_in_place() {
    difference() {
        union() {
            translate([ox0, H - iy1 - wall, wall_top])
                cube([ox1 - ox0, oy1 - oy0, lid_t]);
            // friction lip
            translate([0, 0, wall_top - lip_h]) linear_extrude(lip_h)
                difference() {
                    translate([ix0 + lip_clr, H - iy1 + lip_clr])
                        square([(ix1 - ix0) - 2 * lip_clr,
                                (iy1 - iy0) - 2 * lip_clr]);
                    translate([ix0 + lip_clr + lip_w, H - iy1 + lip_clr + lip_w])
                        square([(ix1 - ix0) - 2 * (lip_clr + lip_w),
                                (iy1 - iy0) - 2 * (lip_clr + lip_w)]);
                }
        }
        // opening above right JST column (J2-J5, strip plugs + wires)
        krect(JST_R[0] - 1.3, JY[0] + JST_DY[0] - 1.3, JST_R[1] + 1.3,
              JY[3] + JST_DY[1] + 1.3, wall_top - lip_h - 1, wall_top + lid_t + 1);
        // opening above left JST column (J7-J10, power plugs). Cut from x=-1,
        // all the way through the lip: the connectors sit so close to the board
        // edge that stopping at the body would leave a 0.7 mm lip sliver.
        krect(-1, JY[0] + JST_DY[0] - 1.3, JST_L[1] + 1.3,
              JY[3] + JST_DY[1] + 1.3, wall_top - lip_h - 1, wall_top + lid_t + 1);
        // J1 access: open to the board edge so supply wires drop in
        krect(35.5, -clr - wall - 2, 49.5, 15, wall_top - lip_h - 1,
              wall_top + lid_t + 1);
    }
}

// lid flipped flat on the print bed (top face down)
module lid_print() {
    translate([0, 0, wall_top + lid_t]) rotate([180, 0, 0]) lid_in_place();
}

// ---------------- ghost board for the assembly view ----------------
module board_ghost() {
    color("darkgreen", 0.85) krect(0, 0, W, H, pcb_bot, pcb_top);
    color("limegreen", 0.9)                        // J1 terminal block
        krect(J1_BOX[0], J1_BOX[1], J1_BOX[2], J1_BOX[3],
              pcb_top, pcb_top + J1_HT);
    color("white", 0.9) for (y = JY) {             // 8x JST XH
        krect(JST_R[0], y + JST_DY[0], JST_R[1], y + JST_DY[1],
              pcb_top, pcb_top + JST_HT);
        krect(JST_L[0], y + JST_DY[0], JST_L[1], y + JST_DY[1],
              pcb_top, pcb_top + JST_HT);
    }
    color("dimgray", 0.9)                          // 2x20 socket on the back
        krect(13.5, 36.5, 67.5, 42.5, pcb_bot - 8.5, pcb_bot);
    color("forestgreen", 0.85)                     // Pi Zero 2 WH
        krect(PI_BOX[0], PI_BOX[1], PI_BOX[2], PI_BOX[3],
              pcb_bot - PI_DROP - PI_T, pcb_bot - PI_DROP);
}

// ---------------- part selection ----------------
if (part == "tray") tray();
if (part == "lid") lid_print();
if (part == "assembly") {
    tray();
    board_ghost();
    color("steelblue", 0.45) translate([0, 0, 12]) lid_in_place();
}

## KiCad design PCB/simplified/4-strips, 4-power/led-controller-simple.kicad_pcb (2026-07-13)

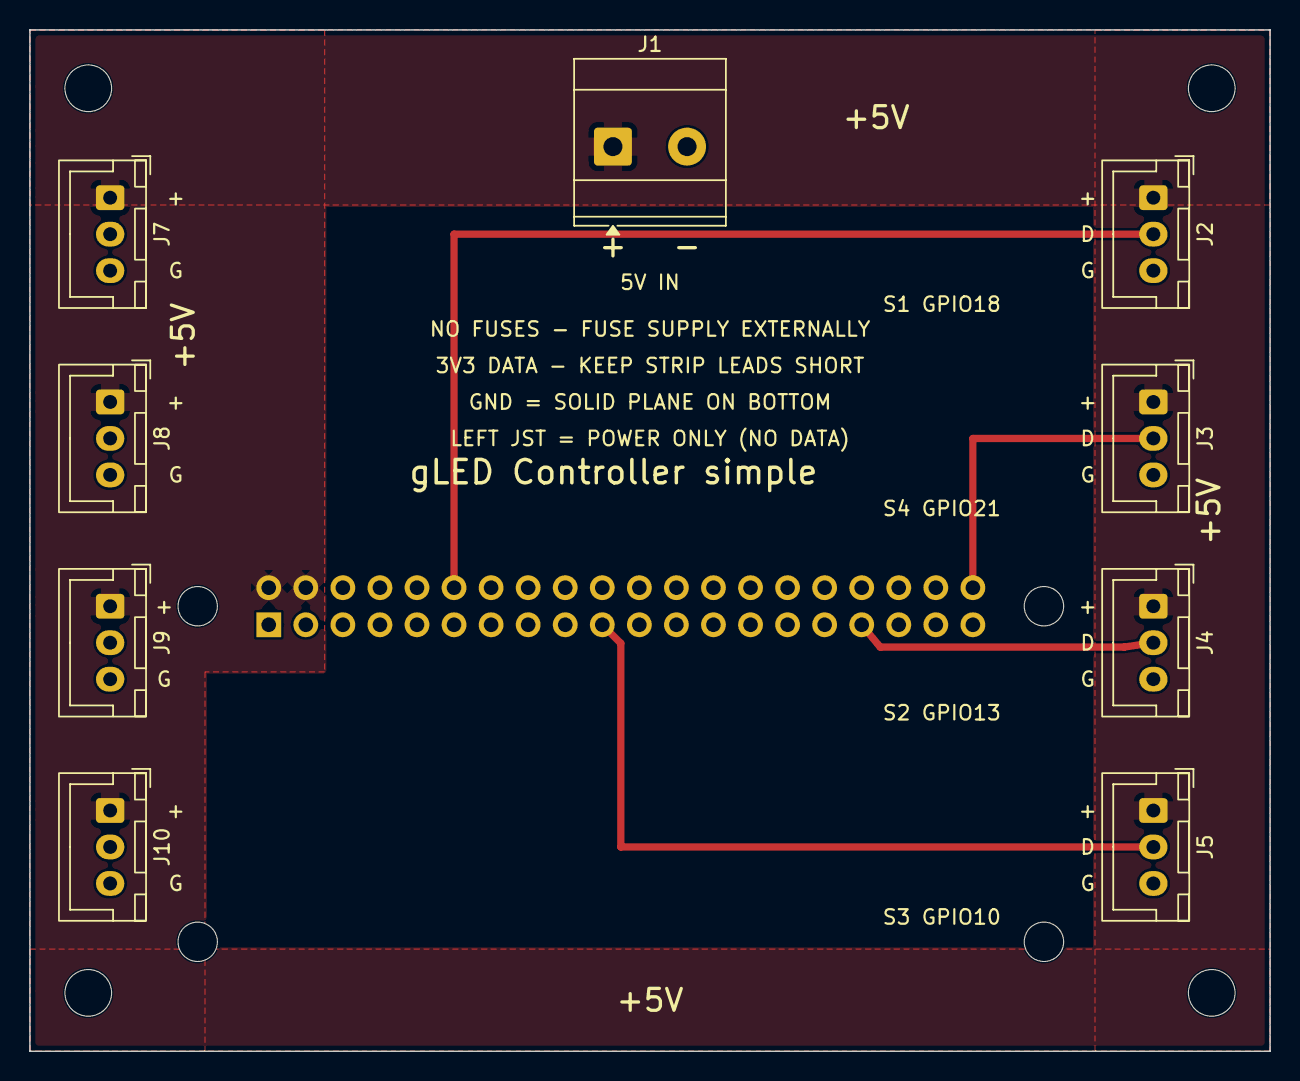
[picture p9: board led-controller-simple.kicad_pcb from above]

Board: 2 copper layers, 85.0 x 70.0 mm, 18 parts (1 on the bottom side), 6 nets.

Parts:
H1, H2, H3, H4: MountingHole_2.7mm_M2.5
H5, H6, H7, H8: MountingHole_3.2mm_M3
J1: 5V IN; TerminalBlock_Phoenix_MKDS-3-2-5.08_1x02_P5.08mm_Horizontal
J2: GPIO18; JST_XH_B3B-XH-A_1x03_P2.50mm_Vertical
J3: GPIO21; JST_XH_B3B-XH-A_1x03_P2.50mm_Vertical
J4: GPIO13; JST_XH_B3B-XH-A_1x03_P2.50mm_Vertical
J5: GPIO10; JST_XH_B3B-XH-A_1x03_P2.50mm_Vertical
J6: Pi Zero 2 WH; PinSocket_2x20_P2.54mm_Vertical
J7, J8, J9, J10: PWR; JST_XH_B3B-XH-A_1x03_P2.50mm_Vertical

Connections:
+5V: J1.1, J2.1, J3.1, J4.1, J5.1, J6.2, J6.4, J7.1, J8.1, J9.1, J10.1
DATA_GPIO10: J5.2, J6.19
DATA_GPIO13: J4.2, J6.33
DATA_GPIO18: J2.2, J6.12
DATA_GPIO21: J3.2, J6.40
GND: J1.2, J2.3, J3.3, J4.3, J5.3, J6.6, J6.9, J6.14, J6.20, J6.25, J6.30, J6.34, J6.39, J7.3, J8.3, J9.3, J10.3

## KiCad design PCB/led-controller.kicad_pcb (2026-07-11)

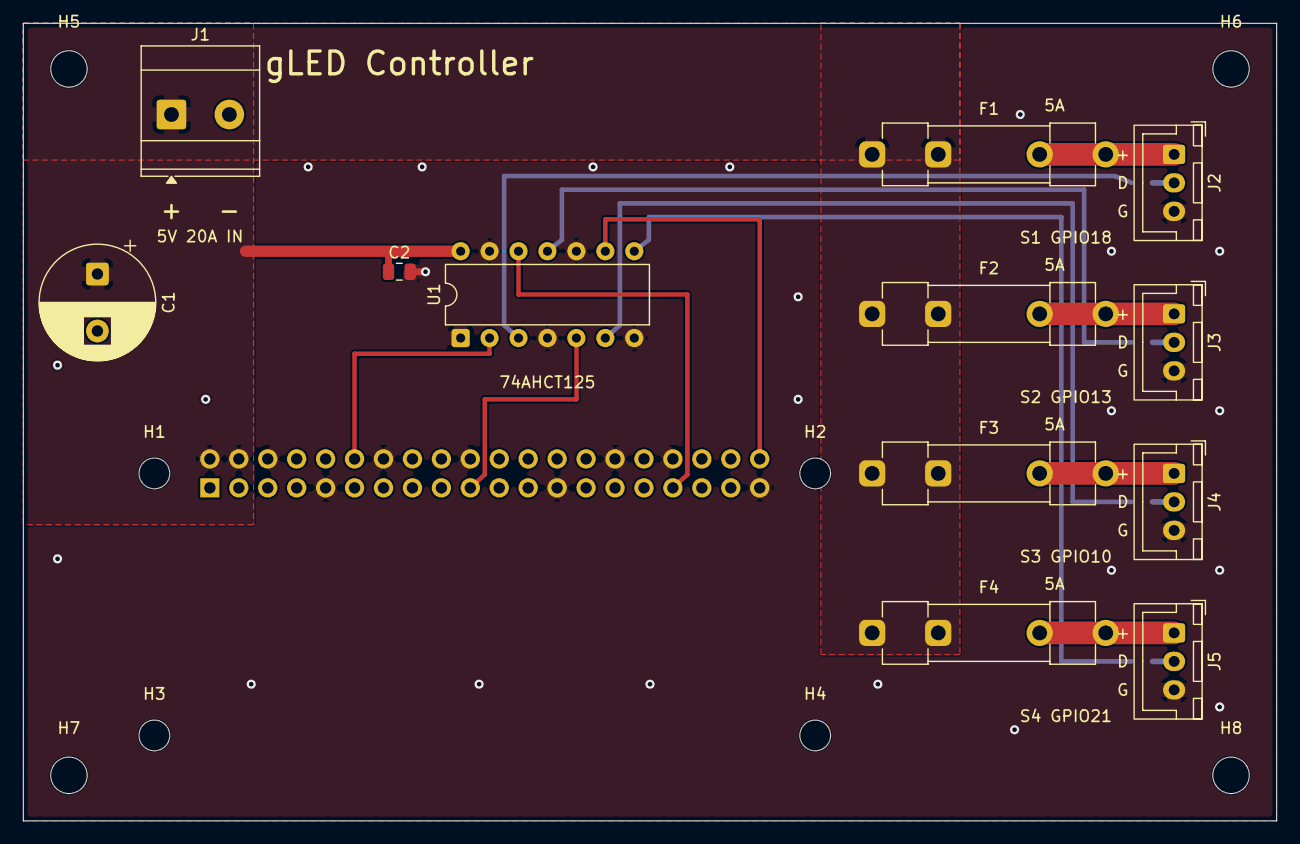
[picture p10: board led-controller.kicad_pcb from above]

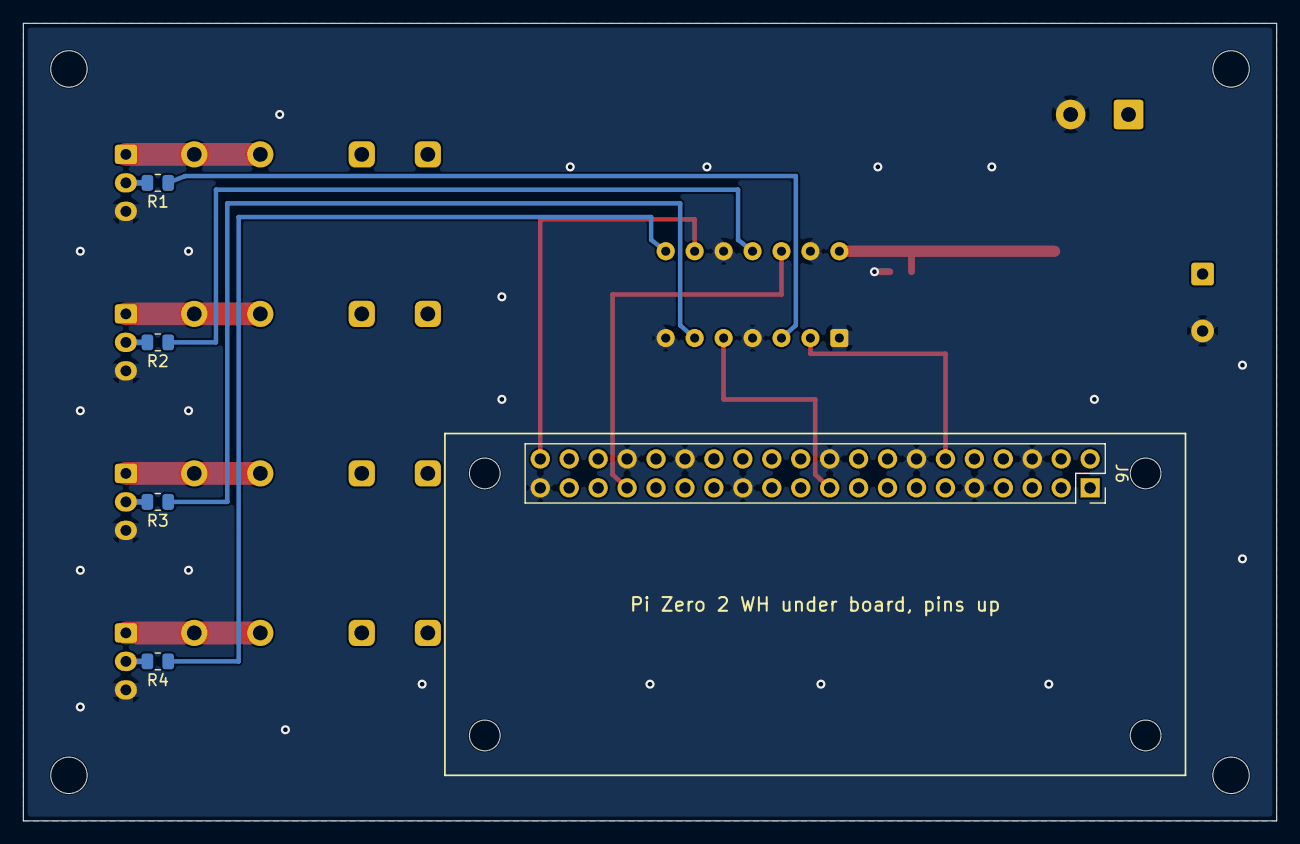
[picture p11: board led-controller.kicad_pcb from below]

Board: 2 copper layers, 110.0 x 70.0 mm, 25 parts (5 on the bottom side), 18 nets.

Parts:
C1: 1000uF 16V; CP_Radial_D10.0mm_P5.00mm
C2: 100nF; C_0805_2012Metric
F1, F2, F3, F4: 5A; Fuseholder_Clip-5x20mm_Littelfuse_520_Inline_P20.50x5.80mm_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
H1, H2, H3, H4: MountingHole_2.7mm_M2.5
H5, H6, H7, H8: MountingHole_3.2mm_M3
J1: 5V IN; TerminalBlock_Phoenix_MKDS-3-2-5.08_1x02_P5.08mm_Horizontal
J2: STRIP1; JST_XH_B3B-XH-A_1x03_P2.50mm_Vertical
J3: STRIP2; JST_XH_B3B-XH-A_1x03_P2.50mm_Vertical
J4: STRIP3; JST_XH_B3B-XH-A_1x03_P2.50mm_Vertical
J5: STRIP4; JST_XH_B3B-XH-A_1x03_P2.50mm_Vertical
J6: Pi Zero 2 WH; PinSocket_2x20_P2.54mm_Vertical
R1, R2, R3, R4: 470R; R_0805_2012Metric
U1: 74AHCT125; DIP-14_W7.62mm

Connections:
5V_S1: F1.2, J2.1
5V_S2: F2.2, J3.1
5V_S3: F3.2, J4.1
5V_S4: F4.2, J5.1
+5V: C1.1, C2.1, F1.1, F2.1, F3.1, F4.1, J1.1, J6.2, J6.4, U1.14
D1_5V: R1.1, U1.3
D2_5V: R2.1, U1.11
D3_5V: R3.1, U1.6
D4_5V: R4.1, U1.8
D10_3V3: J6.19, U1.5
D13_3V3: J6.33, U1.12
D18_3V3: J6.12, U1.2
D21_3V3: J6.40, U1.9
DATA1: J2.2, R1.2
DATA2: J3.2, R2.2
DATA3: J4.2, R3.2
DATA4: J5.2, R4.2
GND: C1.2, C2.2, J1.2, J2.3, J3.3, J4.3, J5.3, J6.6, J6.9, J6.14, J6.20, J6.25, J6.30, J6.34, J6.39, U1.1, U1.4, U1.7, U1.10, U1.13

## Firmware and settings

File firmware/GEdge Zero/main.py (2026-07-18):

#!/usr/bin/env python3
# Entry point: HTTP-controlled 4-strip WS2812/NeoPixel driver for a
# Raspberry Pi Zero family board (Zero W / Zero WH / Zero 2 W), wired per
# "PCB/simplified/4-strips, 4-power". Application code lives in /src,
# animations in /animations, shared color helpers in /glib - same layout as
# firmware/GEdge (the Pico W version). See README.md for setup.

import os
import signal
import sys
import threading
import time

sys.path.append(os.path.dirname(os.path.abspath(__file__)))
sys.path.append(os.path.join(os.path.dirname(os.path.abspath(__file__)), "src"))

import config
from strip_controller import StripController
from animation_runner import AnimationRunner
from led_server import create_server

controllers = {}
runners = {}


def _setup_strips():
    for strip_name, cfg in config.STRIPS.items():
        print("Initializing", strip_name, "on GPIO", cfg["gpio"])
        controllers[strip_name] = StripController(
            gpio=cfg["gpio"],
            num_pixels=cfg["num_pixels"],
            channel=cfg.get("channel", 0),
            dma=cfg.get("dma", 10),
        )
        runners[strip_name] = AnimationRunner(controllers[strip_name])

    default_animations = getattr(config, "DEFAULT_ANIMATIONS", {})
    for strip_name, animation_name in default_animations.items():
        if animation_name and strip_name in runners:
            runners[strip_name].run_animation(animation_name)
            print("Running animation:", animation_name, "on", strip_name)


def _animation_loop():
    # Advances every strip's animation; runs alongside the (blocking) Flask
    # server so all strips keep animating while the server handles requests.
    while True:
        for runner in runners.values():
            runner.update()
        time.sleep(0.02)


def _clear_and_exit(signum, frame):
    print("Shutting down, clearing strips...")
    for controller in controllers.values():
        try:
            controller.clear()
        except Exception as e:  # pylint: disable=broad-except
            print(e)
    sys.exit(0)


def main():
    _setup_strips()

    signal.signal(signal.SIGINT, _clear_and_exit)
    signal.signal(signal.SIGTERM, _clear_and_exit)

    threading.Thread(target=_animation_loop, daemon=True).start()

    app = create_server(controllers, runners)
    print("Server starting on {}:{}".format(config.HOST, config.PORT))
    app.run(host=config.HOST, port=config.PORT)


if __name__ == "__main__":
    main()

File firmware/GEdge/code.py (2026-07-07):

# Entry point: WLAN-controlled NeoPixel LED strip on a Raspberry Pi Pico W.
# Application code lives in /src.

import sys
import time

import board

sys.path.append("/src")

import config
from status_light import StatusLight
from wifi_manager import connect
from pixel_controller import PixelController
from animation_runner import AnimationRunner
from led_server import create_server

time.sleep(1)

# Debug-by-light: off now, blinks while connecting, steady once connected.
status = StatusLight(
    connecting_interval=config.CONNECTING_BLINK_INTERVAL,
    pulse_interval=config.PULSE_BLINK_INTERVAL,
    pulse_count=config.PULSE_COUNT,
)
status.off()

# Connect to WiFi (station mode, static IP) and get a socket pool.
pool = connect(
    config.WIFI_SSID,
    config.WIFI_PASSWORD,
    config.STATIC_IP,
    config.NETMASK,
    config.GATEWAY,
    config.TX_POWER,
    status=status,
)
status.connected()

# Set up the LED strip and the animation runner.
pixels = PixelController(board.GP0, config.NUM_PIXELS)
runner = AnimationRunner(pixels)

# Build and start the HTTP server.
server = create_server(pool, pixels, runner, status=status)
server.start(config.STATIC_IP)
print("Server started at", config.STATIC_IP)

# Animate without a client until someone connects.
if config.DEFAULT_ANIMATION:
    runner.run_animation(config.DEFAULT_ANIMATION)
    print("Running animation:", config.DEFAULT_ANIMATION)

# Main loop: poll the server, advance the animation, drive the status LED.
while True:
    try:
        server.poll()
        runner.update()
        status.update()
    except Exception:  # pylint: disable=broad-except
        continue

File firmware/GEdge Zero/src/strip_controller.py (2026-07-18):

# WS2812/NeoPixel strip control on Raspberry Pi GPIO, via rpi_ws281x.
#
# Mirrors the PixelController interface from
# firmware/GEdge/src/pixel_controller.py (the Pico W version) so
# animation_runner.py and the /animations modules are unchanged. One
# instance drives one physical strip on one GPIO/peripheral (PWM0, PWM1,
# PCM or SPI - see README.md for the pin table).

import time

from rpi_ws281x import PixelStrip, Color


class StripController:
    def __init__(self, gpio, num_pixels, channel=0, dma=10, freq_hz=800000,
                 invert=False, brightness=255):
        self.num_pixels = num_pixels
        self._strip = PixelStrip(
            num_pixels, gpio,
            freq_hz=freq_hz,
            dma=dma,
            invert=invert,
            brightness=brightness,
            channel=channel,
        )
        self._strip.begin()

    def set_pixels(self, data):
        """Apply colors from a "r,g,b|r,g,b|..." string."""
        t_start = time.monotonic()
        for i, color in enumerate(data.split("|")):
            if i >= self.num_pixels:
                break
            r, g, b = (int(c) for c in color.split(","))
            self._strip.setPixelColor(i, Color(r, g, b))
        t_parsed = time.monotonic()
        self._strip.show()
        t_shown = time.monotonic()
        print(
            "set_pixels: parse={:.1f}ms show={:.1f}ms total={:.1f}ms".format(
                (t_parsed - t_start) * 1000,
                (t_shown - t_parsed) * 1000,
                (t_shown - t_start) * 1000,
            )
        )

    def fill(self, color):
        """Set all pixels to one color without showing."""
        r, g, b = color
        packed = Color(r, g, b)
        for i in range(self.num_pixels):
            self._strip.setPixelColor(i, packed)

    def set_pixel(self, i, color):
        """Set a single pixel without showing."""
        r, g, b = color
        self._strip.setPixelColor(i, Color(r, g, b))

    def show(self):
        self._strip.show()

    def set_brightness(self, value):
        """Set strip brightness. Takes a float 0.0-1.0 (same contract as
        GEdge's PixelController); rpi_ws281x itself wants 0-255.
        """
        self._strip.setBrightness(int(max(0.0, min(1.0, value)) * 255))
        self._strip.show()

    def clear(self):
        self.fill((0, 0, 0))
        self.show()

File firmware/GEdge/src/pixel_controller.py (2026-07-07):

# NeoPixel strip control, decoupled from the HTTP server.

import time

import neopixel


class PixelController:
    def __init__(self, pin, num_pixels, order=neopixel.GRB, brightness=1.0):
        self.num_pixels = num_pixels
        self.pixels = neopixel.NeoPixel(
            pin,
            num_pixels,
            brightness=brightness,
            auto_write=False,
            pixel_order=order,
        )

    def set_pixels(self, data):
        """Apply colors from a "r,g,b|r,g,b|..." string."""
        t_start = time.monotonic()
        for i, color in enumerate(data.split("|")):
            if i >= self.num_pixels:
                break
            r, g, b = (int(c) for c in color.split(","))
            self.pixels[i] = (r, g, b)
        t_parsed = time.monotonic()
        self.pixels.show()
        t_shown = time.monotonic()
        print(
            "set_pixels: parse={:.1f}ms show={:.1f}ms total={:.1f}ms".format(
                (t_parsed - t_start) * 1000,
                (t_shown - t_parsed) * 1000,
                (t_shown - t_start) * 1000,
            )
        )

    def fill(self, color):
        """Set all pixels to one color without showing."""
        self.pixels.fill(color)

    def set_pixel(self, i, color):
        """Set a single pixel without showing."""
        self.pixels[i] = color

    def show(self):
        self.pixels.show()

    def set_brightness(self, value):
        """Set strip brightness. NeoPixel expects a float in 0.0 - 1.0."""
        self.pixels.brightness = max(0.0, min(1.0, value))
        self.pixels.show()

    def clear(self):
        self.pixels.fill((0, 0, 0))
        self.pixels.show()

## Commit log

2026-07-09 Add wire behavior calculator with Ohm's law and thermal analysis
2026-07-11 Add PCB trace support and thermal analysis to wire behavior calculator
2026-07-11 Add LED controller PCB design and documentation
2026-07-11 Add bill of materials (BOM) for PCB components
    [bom.csv]
2026-07-11 Add KiCad files for LED controller PCB design and build scripts
    [led-controller-B_Cu.gbl, led-controller-B_Mask.gbs, led-controller-B_Silkscreen.gbo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]
2026-07-12 Add simplified LED controller PCB design and associated files
    [bom.csv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]
2026-07-12 moved files
    [bom.csv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]
2026-07-13 new layout for additional power
    [bom.csv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]
2026-07-13 Add 3D-printable case design for gLED Controller
    [case.scad, case_lid.stl, case_tray.stl]
2026-07-18 Add shutdown capability and power button for GEdge Zero controller
    [bom.csv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]
